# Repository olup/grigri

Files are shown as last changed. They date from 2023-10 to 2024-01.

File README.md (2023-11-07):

# grigri
Grigri - the open storyteller

<p xmlns:cc="http://creativecommons.org/ns#" xmlns:dct="http://purl.org/dc/terms/"><a property="dct:title" rel="cc:attributionURL" href="https://github.com/olup/grigri">Grigri</a> by <a rel="cc:attributionURL dct:creator" property="cc:attributionName" href="https://github.com/olup">the grigri team</a> is licensed under <a href="http://creativecommons.org/licenses/by-nc/4.0/?ref=chooser-v1" target="_blank" rel="license noopener noreferrer" style="display:inline-block;">CC BY-NC 4.0</a></p>

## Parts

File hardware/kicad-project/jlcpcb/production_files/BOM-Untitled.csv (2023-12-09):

Comment | Designator | Footprint | LCSC
DMG2301L-7 | Q1,Q3 | SOT-23-3_L2.9-W1.3-P1.90-LS2.4-BR | C102619
MCP73831-2ACI/MC | U2 | TDFN-8_L3.0-W2.0-P0.50-BL-EP1.6 | C150772
1N5819WS | D1 | SOD-323_L1.8-W1.3-LS2.5-RD | C191023
KT-0603R | CHARGE_LED1 | LED0603-RD | C2286
USBLC6-2SC6_C2687116 | D2 | SOT-23-6_L2.9-W1.6-P0.95-LS2.8-BL | C2687116
TYPE-C 16PIN 2MD(073) | USB1 | USB-C-SMD_TYPE-C-6PIN-2MD-073 | C2765186
ST-0322D00-071-1A2H | CN2 | AUDIO-TH_ST-0322D00-071-1A2H | C2829970
ESP32-S3-WROOM-1(N8R2) | U1 | WIRELM-SMD_ESP32-S3-WROOM-1 | C2913204
GT-TC054C-H035-L1W | SW5,SW6,SW7 | KEY-SMD_4P-L7.8-W2.8-P4.20-EH | C3020033
Battery connector | H1,H2 | CONN-SMD_2P-P2.00_XUNPU_WAFER-PH2.0-2PWB | C3029440
TS-1187A-B-A-B | SW10,SW9 | SW-SMD_4P-L5.1-W5.1-P3.70-LS6.5-TL-2 | C318884
E6C1209RGBC3UDA | LED1 | LED-ARRAY-SMD_4P-L3.2-W2.7-TL-1 | C375572
TF PUSH | Card1 | TF-SMD_TF-PUSH | C393941
ME6217C33P5G | U3 | SOT-89-5_L4.5-W2.5-P1.50-LS4.5-BR | C81592
MAX98357AETE+T | U6 | TQFN-16_L3.0-W3.0-P0.50-BL-EP1.5 | C910544
K2-1109SP-C4SA | SW1,SW2,SW3,SW4 | KEY-SMD_4P-L4.5-W4.5-P3.00-LS7.0 | C92570
3k | R14 | R_0805_2012Metric
10k | R27 | R_0805_2012Metric
10k | R3 | R_0805_2012Metric
10k | R31 | R_0805_2012Metric
10uF | C18 | C_0805_2012Metric
mhole | H5 | MountingHole_3.2mm_M3_ISO7380_Pad
10uF | C19 | C_0805_2012Metric
10 | R1 | R_0805_2012Metric
0.1uF | C8 | C_0805_2012Metric
mhole | H6 | MountingHole_3.2mm_M3_ISO7380_Pad
1M | R5 | R_0805_2012Metric
1uF | C11 | C_0805_2012Metric
10uF | C3 | C_0805_2012Metric
10uF | C2 | C_0805_2012Metric
10k | R28 | R_0805_2012Metric
10k | R40 | R_0805_2012Metric
10 | R17 | R_0805_2012Metric
5.1k | R15 | R_0805_2012Metric
1M | R4 | R_0805_2012Metric
100nF | C20 | C_0805_2012Metric
10uF | C17 | C_0805_2012Metric
4.7uF | C10 | C_0805_2012Metric
4.7uF | C9 | C_0805_2012Metric
10uf | C12 | C_0805_2012Metric
10k | R29 | R_0805_2012Metric
mhole | H3 | MountingHole_3.2mm_M3_ISO7380_Pad
10k | R12 | R_0805_2012Metric
10uF | C7 | C_0805_2012Metric
Conn_01x50 | J8 | FPC-SMD_AFC01-S50FCC-00
10 | R2 | R_0805_2012Metric
2K2 | R16 | R_0805_2012Metric
10k | R30 | R_0805_2012Metric
mhole | H4 | MountingHole_3.2mm_M3_ISO7380_Pad
0 | R18 | R_0805_2012Metric
30 | R8 | R_0805_2012Metric
100k | R33 | R_0805_2012Metric
330 | R6 | R_0805_2012Metric
10k | R26 | R_0805_2012Metric
5.1k | R13 | R_0805_2012Metric
10uF | C16 | C_0805_2012Metric
1uf | C14 | C_0805_2012Metric
0 | R19 | R_0805_2012Metric
10 | R11 | R_0805_2012Metric
10uF | C1 | C_0805_2012Metric
30 | R9 | R_0805_2012Metric
330 | R32 | R_0805_2012Metric
120 | R10 | R_0805_2012Metric
100nF | C5 | C_0805_2012Metric
10uf | C4 | C_0805_2012Metric
10uF | C15 | C_0805_2012Metric
0 | R7 | R_0805_2012Metric

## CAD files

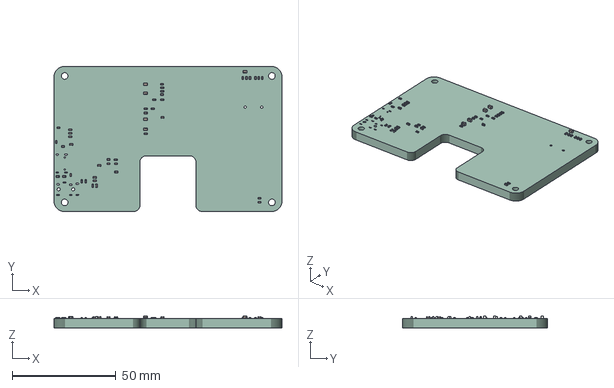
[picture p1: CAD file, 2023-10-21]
hardware/kicad-project/Untitled.step
110.0 x 70.0 x 5.97 mm
_autosave-Untitled PCB

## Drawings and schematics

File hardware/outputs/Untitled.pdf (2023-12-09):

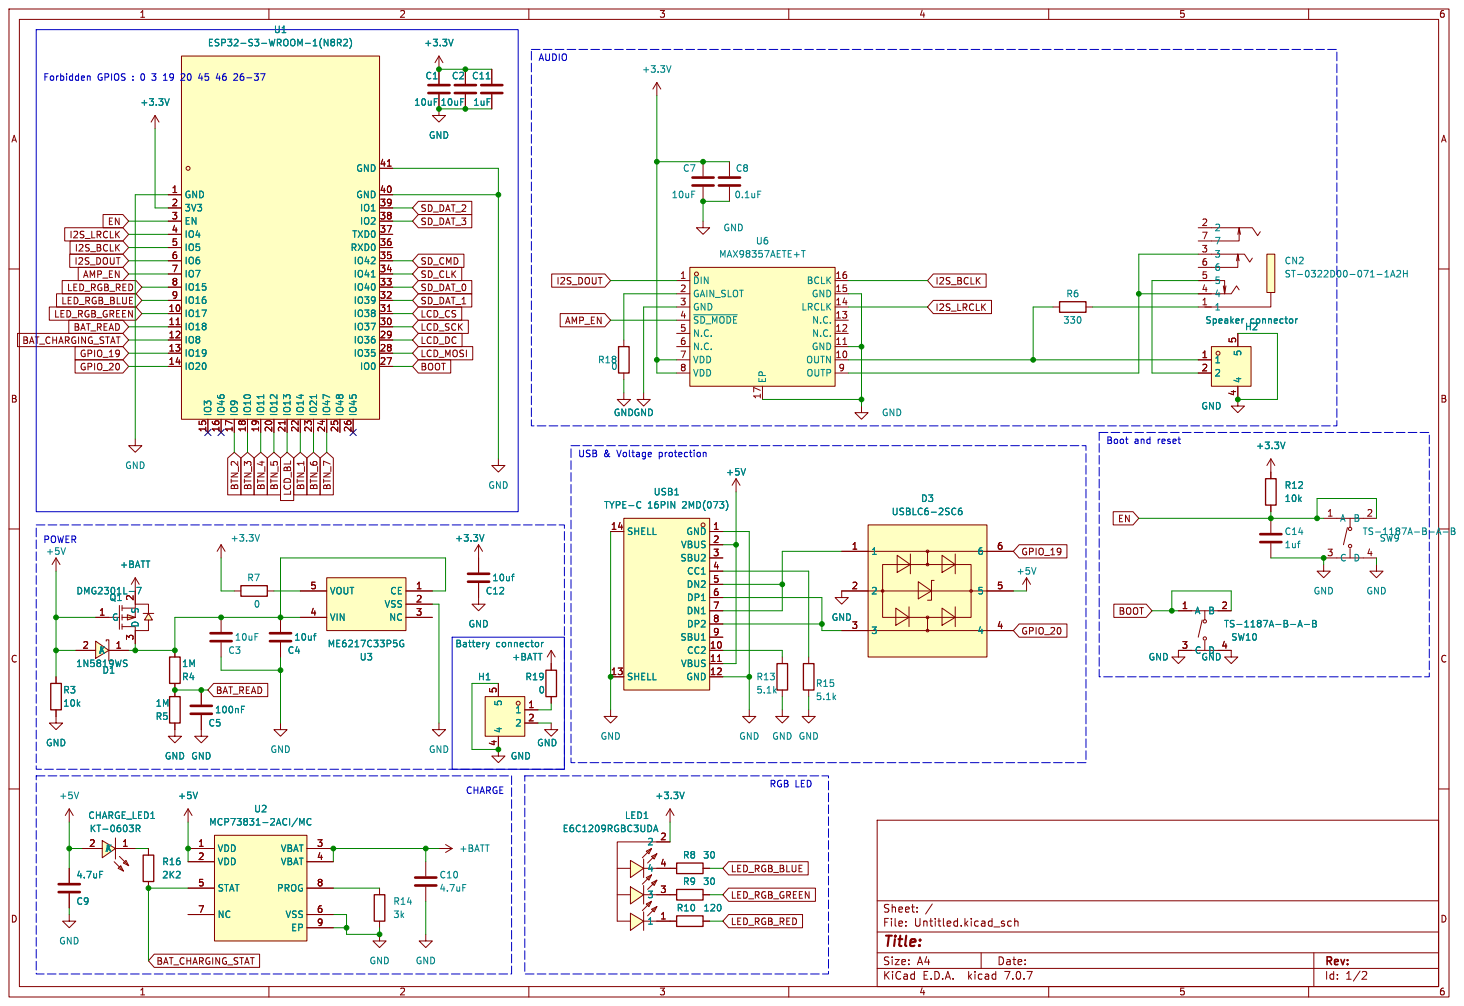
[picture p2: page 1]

Id: 1/2 Title: File: Untitled.kicad_sch Sheet: /

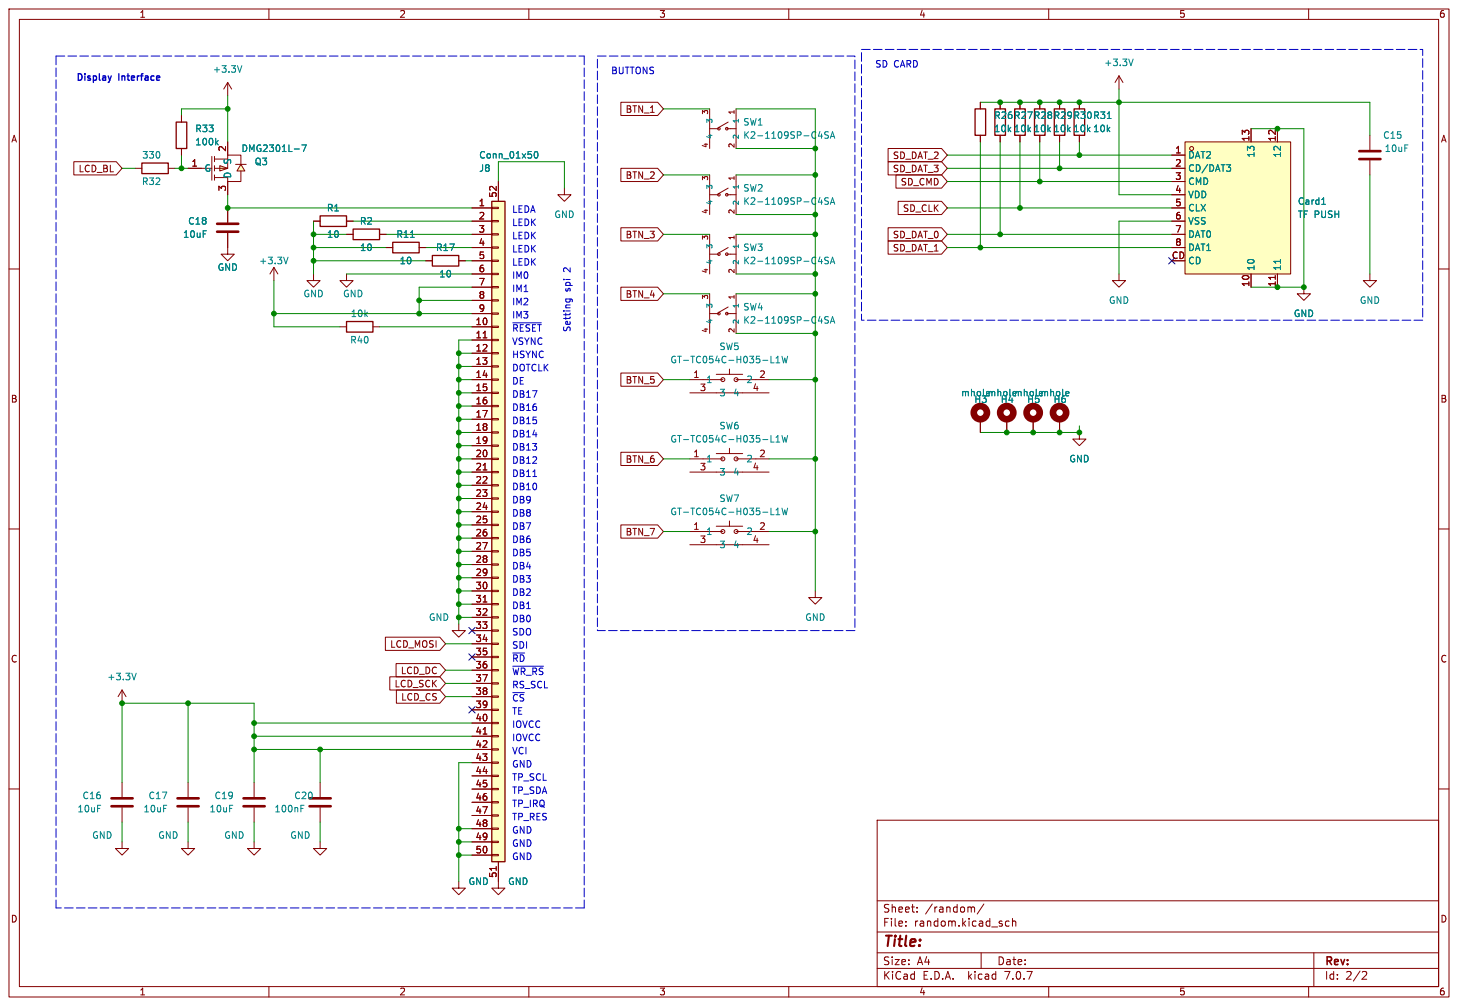
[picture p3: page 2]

Id: 2/2 Title: File: random.kicad_sch Sheet: /random/

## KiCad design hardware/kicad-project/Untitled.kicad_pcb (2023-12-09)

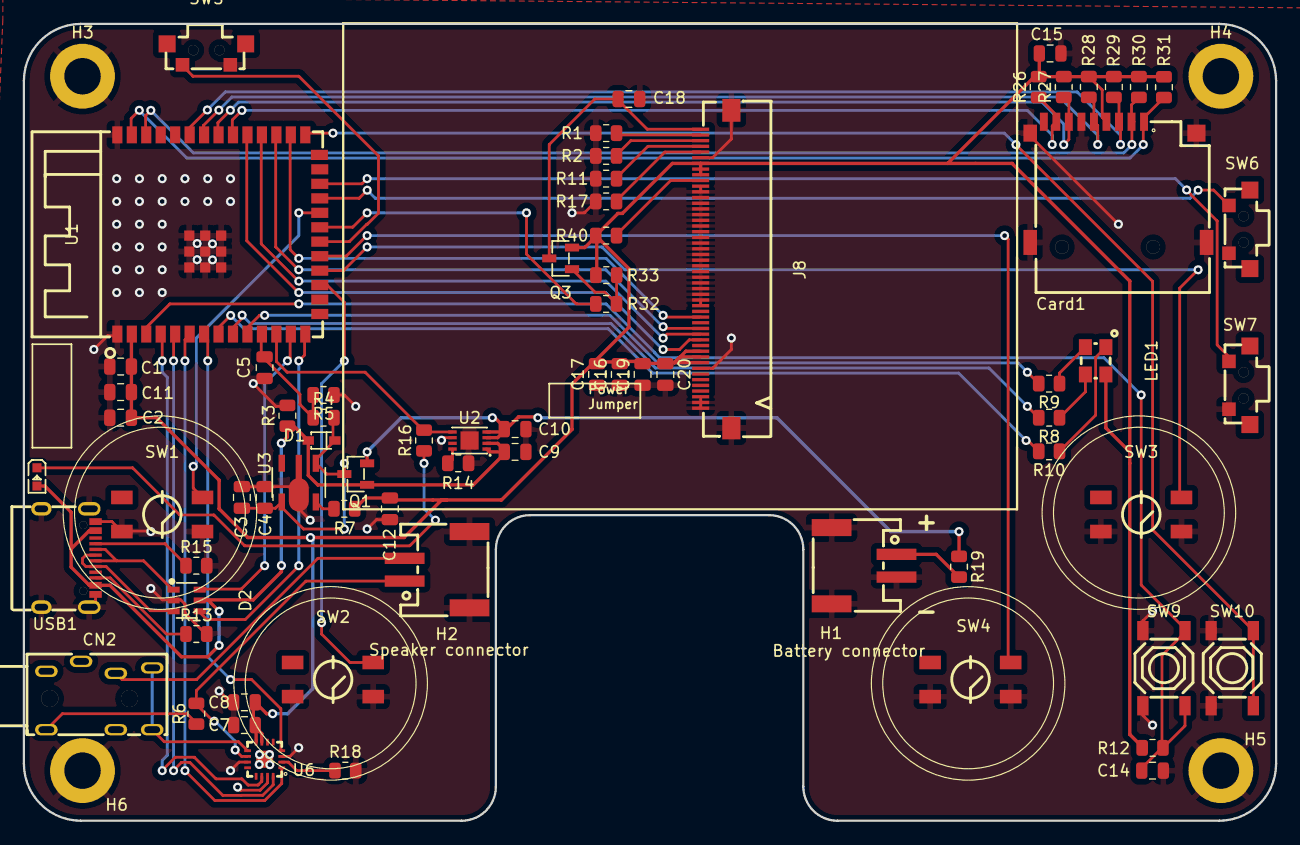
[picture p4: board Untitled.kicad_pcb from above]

Board: 2 copper layers, 110.0 x 70.0 mm, 75 parts (0 on the bottom side), 59 nets.

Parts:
C1, C2, C3, C7, C15, C16, C17, C18, C19: 10uF; C_0805_2012Metric
C4, C12: 10uf; C_0805_2012Metric
C5, C20: 100nF; C_0805_2012Metric
C8: 0.1uF; C_0805_2012Metric
C9, C10: 4.7uF; C_0805_2012Metric
C11: 1uF; C_0805_2012Metric
C14: 1uf; C_0805_2012Metric
CHARGE_LED1: KT-0603R; LED0603-RD
CN2: ST-0322D00-071-1A2H; AUDIO-TH_ST-0322D00-071-1A2H
Card1: TF PUSH; TF-SMD_TF-PUSH
D1: 1N5819WS; SOD-323_L1.8-W1.3-LS2.5-RD
D2: USBLC6-2SC6_C2687116; SOT-23-6_L2.9-W1.6-P0.95-LS2.8-BL
H1: Battery connector; CONN-SMD_2P-P2.00_XUNPU_WAFER-PH2.0-2PWB
H2: Speaker connector; CONN-SMD_2P-P2.00_XUNPU_WAFER-PH2.0-2PWB
H3, H4, H5, H6: mhole; MountingHole_3.2mm_M3_ISO7380_Pad
J8: Conn_01x50; FPC-SMD_AFC01-S50FCC-00
LED1: E6C1209RGBC3UDA; LED-ARRAY-SMD_4P-L3.2-W2.7-TL-1
Q1, Q3: DMG2301L-7; SOT-23-3_L2.9-W1.3-P1.90-LS2.4-BR
R1, R2, R11, R17: 10; R_0805_2012Metric
R3, R12, R26, R27, R28, R29, R30, R31, R40: 10k; R_0805_2012Metric
R4, R5: 1M; R_0805_2012Metric
R6, R32: 330; R_0805_2012Metric
R7, R18, R19: 0; R_0805_2012Metric
R8, R9: 30; R_0805_2012Metric
R10: 120; R_0805_2012Metric
R13, R15: 5.1k; R_0805_2012Metric
R14: 3k; R_0805_2012Metric
R16: 2K2; R_0805_2012Metric
R33: 100k; R_0805_2012Metric
SW1, SW2, SW3, SW4: K2-1109SP-C4SA; KEY-SMD_4P-L4.5-W4.5-P3.00-LS7.0
SW5, SW6, SW7: GT-TC054C-H035-L1W; KEY-SMD_4P-L7.8-W2.8-P4.20-EH
SW9, SW10: TS-1187A-B-A-B; SW-SMD_4P-L5.1-W5.1-P3.70-LS6.5-TL-2
U1: ESP32-S3-WROOM-1(N8R2); WIRELM-SMD_ESP32-S3-WROOM-1
U2: MCP73831-2ACI/MC; TDFN-8_L3.0-W2.0-P0.50-BL-EP1.6
U3: ME6217C33P5G; SOT-89-5_L4.5-W2.5-P1.50-LS4.5-BR
U6: MAX98357AETE+T; TQFN-16_L3.0-W3.0-P0.50-BL-EP1.5
USB1: TYPE-C 16PIN 2MD(073); USB-C-SMD_TYPE-C-6PIN-2MD-073

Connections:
+3.3V: C1.2, C2.2, C7.2, C8.2, C11.2, C12.2, C15.2, C16.2, C17.2, C19.2, C20.1, Card1.4 (VDD), J8.7, J8.8, J8.9, J8.40, J8.41, J8.42 (Pin_41), LED1.2, Q3.2 (S), R7.1, R12.1, R26.2, R27.2, R28.2, R29.2, R30.2, R31.2, R33.2, R40.1, U1.2 (3V3), U6.7 (VDD), U6.8 (VDD)
+5V: C9.1, CHARGE_LED1.2 (A), D1.2 (A), D2.5 (VBUS), Q1.1 (G), R3.1, U2.1 (VDD), U2.2 (VDD), USB1.2 (VBUS), USB1.11 (VBUS)
+BATT: C10.1, Q1.2 (S), R19.1, U2.3 (VBAT), U2.4 (VBAT)
AMP_EN: U1.7 (IO7), U6.4 (~SD_MODE)
BAT_CHARGING_STAT: R16.2, U1.12 (IO8), U2.5 (STAT)
BAT_READ: C5.2, R4.1, R5.2, U1.11 (IO18)
BOOT: SW10.1 (A), SW10.2 (B), U1.27 (IO0)
BTN_1: SW1.3, U1.22 (IO14)
BTN_2: SW2.3, U1.17 (IO9)
BTN_3: SW3.3, U1.18 (IO10)
BTN_4: SW4.3, U1.19 (IO11)
BTN_5: SW5.1, U1.20 (IO12)
BTN_6: SW6.1, U1.23 (IO21)
BTN_7: SW7.1, U1.24 (IO47)
EN: C14.1, R12.2, SW9.1 (A), SW9.2 (B), U1.3 (EN)
GND: C1.1, C2.1, C3.1, C4.1, C5.1, C7.1, C8.1, C9.2, C10.2, C11.1, C12.1, C14.2, C15.1, C16.1, C17.1, C18.1, C19.1, C20.2, Card1.6 (VSS), Card1.10, Card1.11, Card1.12, Card1.13, D2.2 (GND), H1.2, H1.4, H1.5, H2.4, H2.5, H3.1, H4.1, H5.1, H6.1, J8.6, J8.11, J8.12, J8.13, J8.14, J8.15, J8.16, J8.17, J8.18, J8.19, J8.20, J8.21, J8.22, J8.23, J8.24, J8.25, J8.26, J8.27, J8.28, J8.29, J8.30, J8.31, J8.32, J8.43, J8.48, J8.49, J8.50, J8.51 (MP), J8.52 (MP), R1.2, R2.2, R3.2, R5.1, R11.2, R13.2, R14.2, R15.2, R17.2, R18.2, SW1.1, SW1.2, SW2.1, SW2.2, SW3.1, SW3.2, SW4.1, SW4.2, SW5.2, SW6.2, SW7.2, SW9.3 (C), SW9.4 (D), SW10.3 (C), SW10.4 (D), U1.1 (GND), U1.40 (GND), U1.41 (GND), U2.6 (VSS), U2.9 (EP), U3.2 (VSS), U6.3 (GND), U6.11 (GND), U6.15 (GND), U6.17 (EP), USB1.1 (GND), USB1.12 (GND), USB1.13 (SHELL), USB1.14 (SHELL)
GPIO_19: D2.6 (I/O1), U1.13 (IO19)
GPIO_20: D2.4 (I/O2), U1.14 (IO20)
I2S_BCLK: U1.5 (IO5), U6.16 (BCLK)
I2S_DOUT: U1.6 (IO6), U6.1 (DIN)
I2S_LRCLK: U1.4 (IO4), U6.14 (LRCLK)
LCD_BL: R32.2, U1.21 (IO13)
LCD_CS: J8.38, U1.31 (IO38)
LCD_DC: J8.36, U1.29 (IO36)
LCD_MOSI: J8.34, U1.28 (IO35)
LCD_SCK: J8.37, U1.30 (IO37)
LED_RGB_BLUE: R8.2, U1.9 (IO16)
LED_RGB_GREEN: R9.2, U1.10 (IO17)
LED_RGB_RED: R10.2, U1.8 (IO15)
unnamed: CHARGE_LED1.1 (K), R16.1
unnamed: CN2.1, R6.1
unnamed: CN2.5, H2.2
unnamed: C3.2, C4.2, D1.1 (K), Q1.3 (D), R4.2, U3.1 (CE), U3.4 (VIN)
unnamed: H1.1, R19.2
unnamed: C18.2, J8.1, Q3.3 (D)
unnamed: J8.2, R1.1
unnamed: J8.3, R2.1
unnamed: J8.4, R11.1
unnamed: J8.5, R17.1
unnamed: J8.10, R40.2
unnamed: LED1.1, R10.1
unnamed: LED1.3, R9.1
unnamed: LED1.4, R8.1
unnamed: Q3.1 (G), R32.1, R33.1
unnamed: R14.1, U2.8 (PROG)
unnamed: R7.2, U3.5 (VOUT)
unnamed: R18.1, U6.2 (GAIN_SLOT)
unnamed: H2.1, R6.2, U6.10 (OUTN)
unnamed: CN2.3, CN2.4, U6.9 (OUTP)
unnamed: R15.1, USB1.4 (CC1)
unnamed: R13.1, USB1.10 (CC2)
unnamed: D2.1 (I/O1), USB1.5 (DN2), USB1.7 (DN1)
unnamed: D2.3 (I/O2), USB1.6 (DP1), USB1.8 (DP2)
SD_CLK: Card1.5 (CLX), R28.1, U1.34 (IO41)
SD_CMD: Card1.3 (CMD), R29.1, U1.35 (IO42)
SD_DAT_0: Card1.7 (DAT0), R27.1, U1.33 (IO40)
SD_DAT_1: Card1.8 (DAT1), R26.1, U1.32 (IO39)
SD_DAT_2: Card1.1 (DAT2), R31.1, U1.39 (IO1)
SD_DAT_3: Card1.2 (CD/DAT3), R30.1, U1.38 (IO2)

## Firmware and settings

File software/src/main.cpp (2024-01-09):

#include <Arduino.h>
#include <ArduinoJson.h>
#include <Button2.h>

#include "./BLE/manager.h"
#include "./GlobalNav/GlobalNav.h"
#include "./define.h"
#include "./display/display.h"
#include "./file/file.h"
#include "./player/player.h"
#include "./power.h"
#include "./settings/settings.h"
#include "./utils/utils.h"
#include "./wifi/wifi.h"
#include "soc/rtc_cntl_reg.h"
#include "soc/soc.h"

#define SOURCE_DIR "/grigri"
#define PACKS_DIR "packs/"

GlobalNav globalNav;
BLEManager bleManager;
WiFiModule wifiModule;

Button2 btn1;
Button2 btn2;
Button2 btn3;
Button2 btn4;
Button2 btn5;
Button2 btn6;
Button2 btn7;

void play_selection() {
  state_is_paused = false;

  state_nav_pack = globalNav.getCurrentPackUuid();
  state_nav_node = globalNav.getCurrentNodeUuid();

  if (globalNav.isStoryNode()) {
    display_set_bl(0);
    cancelShutoff();
  } else {
    display_set_bl(settings_brightness);
    scheduleShutOff();
  }

  player_play(globalNav.getAudioPath().c_str());
  display_draw_image(globalNav.getImagePath().c_str());
}

void audio_eof_mp3(const char* info) {  // end of file
  Serial.println("End of playback");

  if (globalNav.isAutoPlay()) {
    Serial.println("Autoplay detected");
    globalNav.goToSelect();

    play_selection();
  };
}

void handleTapSelect(Button2& b) {
  delaySwitchOff();

  if (state_is_paused) {
    player_togglePause();
    display_set_bl(0);
    state_is_paused = false;
    return;
  }

  if (player_isPlaying() && globalNav.isStoryNode()) {
    state_nav_pos = player_get_position();
    player_togglePause();
    display_pause();
    display_set_bl(settings_brightness);
    state_is_paused = true;
    return;
  }

  Serial.println("Action: Select");
  globalNav.goToSelect();

  play_selection();
}

void handleTapBack(Button2& b) {
  delaySwitchOff();

  Serial.println("Action: Back");

  if (globalNav.isCoverNode()) {
    return;
  }

  globalNav.goToBack();
  play_selection();
}

void handleTapNext(Button2& b) {
  delaySwitchOff();

  Serial.println("Action: Next");

  if (globalNav.isStoryNode() && player_isPlaying()) {
    Serial.println("Playback: +10s");
    player_moveRelative(10);
    return;
  }

  globalNav.goToNext();
  play_selection();
}

void handleTapPrevious(Button2& b) {
  delaySwitchOff();

  Serial.println("Action: Previous");

  if (globalNav.isStoryNode() && player_isPlaying()) {
    Serial.println("Playback: -10s");
    player_moveRelative(-10);
    return;
  }

  globalNav.goToPrevious();

  play_selection();
}

void handleVolumeUp(Button2& b) {
  delaySwitchOff();
  settings_volume = settings_volume + 10;
  if (settings_volume > 100) settings_volume = 100;
  player_setVolume(settings_volume);
}
void handleVolumeDown(Button2& b) {
  delaySwitchOff();
  settings_volume = settings_volume - 10;
  if (settings_volume < 0) settings_volume = 0;
  player_setVolume(settings_volume);
}

void handlePreSwitchOff(Button2& b) { display_set_bl(0); }

void handleSwitchOff(Button2& b) {
  delay(100);
  Serial.println("Switch off");
  switchOff();
}

void handleStartConfigMode(Button2& b) {
  Serial.println("Start config mode");
  state_is_connect_mode = true;
  bleManager.init();
}

void buttons_loop() {
  btn1.loop();
  btn2.loop();
  btn3.loop();
  btn4.loop();
  btn5.loop();
  btn6.loop();
  btn7.loop();
}

void setup() {
  // WRITE_PERI_REG(RTC_CNTL_BROWN_OUT_REG, 0);  // disable brownout detector

  Serial.begin(115200);

  printWakeupReason();

  wifiModule.init();

  // disable radio for power saving
  wifiModule.turnOffWiFi();
  bleManager.switchOff();

  // setup buttons
  btn1.begin(BTN_1);
  btn1.setTapHandler(handleTapPrevious);

  btn2.begin(BTN_2);
  btn2.setTapHandler(handleTapNext);

  btn3.begin(BTN_3);
  btn3.setTapHandler(handleTapBack);

  btn4.begin(BTN_4);
  btn4.setTapHandler(handleTapSelect);

  btn5.begin(BTN_5);
  btn5.setLongClickTime(3000);
  btn5.setLongClickHandler(handleSwitchOff);
  btn5.setLongClickDetectedHandler(handlePreSwitchOff);

  // switch on config mode (enable bluetooth)
  btn5.setDoubleClickHandler(handleStartConfigMode);

  btn6.begin(BTN_6);
  btn6.setTapHandler(handleVolumeUp);

  btn7.begin(BTN_7);
  btn7.setTapHandler(handleVolumeDown);

  // initialize components
  fs_init();
  settings_init();

  display_set_bl(0);
  display_init();

  player_init();

  // initialize navigation
  String jsonPath = mergeSegments(SOURCE_DIR, "/", "packsIndex.json", nullptr);
  String packsDirectoryPath = mergeSegments(SOURCE_DIR, "/", "packs", nullptr);

  globalNav.init(jsonPath.c_str(), packsDirectoryPath.c_str());

  // setup volume and backlight
  display_set_bl(settings_brightness);
  player_setVolume(settings_volume);

  // load navigation position
  if (settings_persist_nav && state_nav_pack.length() > 0 &&
      state_nav_node.length() > 0) {
    globalNav.goTo(state_nav_pack.c_str(), state_nav_node.c_str());

    if (globalNav.isStoryNode()) {
      player_play(globalNav.getAudioPath().c_str(), 30);
      player_togglePause();
      state_is_paused = true;

      // display pause screen
      display_set_bl(settings_brightness);
      display_pause();
    } else {
      play_selection();
    }
  } else {
    play_selection();
  }
}

void loop() {
  player_loop();
  buttons_loop();
}

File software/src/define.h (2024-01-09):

#pragma once

// buttons
#define BTN_1 14
#define BTN_2 9
#define BTN_3 10
#define BTN_4 11
#define BTN_5 12
#define BTN_6 21
#define BTN_7 47

#define WAKE_UP_BTN GPIO_NUM_12

// sound
#define I2S_DOUT 6
#define I2S_BCLK 5
#define I2S_LRC 4

#define AMP_EN 7

// display
// display definition is overriden by the Pio build env, set it there. cf:
// https://github.com/Bodmer/TFT_eSPI/blob/master/docs/PlatformIO/Configuring%20options.txt
#define LCD_BL 13

// sd card
#define CLK 41
#define CMD 42
#define D0 40
#define D1 39
#define D2 1
#define D3 2

// battery
#define BATTERY_READ 18
#define BATTERY_CHARGING_STAT 8

// led
#define LED_RGB_RED 15
#define LED_RGB_GREEN 17
#define LED_RGB_BLUE 16

#define AUDIO_LOG 1

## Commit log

2023-10-21 add outputs
    [Untitled.kicad_pcb, Untitled.kicad_sch]
2023-10-25 update MAX sdmode to 634k R
    [Untitled.kicad_pcb, Untitled.kicad_sch]
2023-10-26 fix mosfet
    [Untitled.kicad_pcb, Untitled.kicad_sch]
2023-11-08 New side buttons
    [Untitled.kicad_pcb, Untitled.kicad_sch, random.kicad_sch]
2023-12-06 rev2 almost there
    [Untitled.kicad_pcb, Untitled.kicad_sch, random.kicad_sch]
2023-12-09 rev 4
    [BOM-Untitled.csv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]
2023-12-28 Auto switch off
2023-12-28 prevent going back when cover node
    [GlobalNav.cpp, main.cpp]
2023-12-31 feat: print wakeup reason
2024-01-01 better switch off
2024-01-06 PWM frequency change
2024-01-07 persist player position and cacel switch off on config mode
2024-02-24 change of LDO in schematics
    [random.kicad_sch]
